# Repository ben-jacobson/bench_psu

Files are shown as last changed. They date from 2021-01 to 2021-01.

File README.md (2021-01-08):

Schematics and ARM Mbed code for a basic adjustable DC bench power supply.

This uses an STM32 MCU to control two channels of adjustable switch mode power supply. Two rotary encoders allow adjustment for voltage on each channel, along with a push button to switch between coarse and fine voltage adjustments. This design makes use of a 12 bit ADC to measure the voltage so that adjustment is made based on measured voltage. 

Each power supply ranges uses the LM2674 which ranges from 1.21V to VDD and is capable of delivering 500mA current. For now there is no current control.

You will need to supply your own 24V DC power supply which is recommended at least 1A. I used a switch mode 24V supply so that there is no need for any additional cooling. The LM2674 maxes out at 36V, but I have not tested anything higher than 24V

Mostly these parts were chosen because I had most of this on hand. This was designed to be an ultra budget build making use of parts from old projects, and to teach me how to build a basic PSU. In future, I'd like to build something that allows current limiting with a 0V to 36V range.

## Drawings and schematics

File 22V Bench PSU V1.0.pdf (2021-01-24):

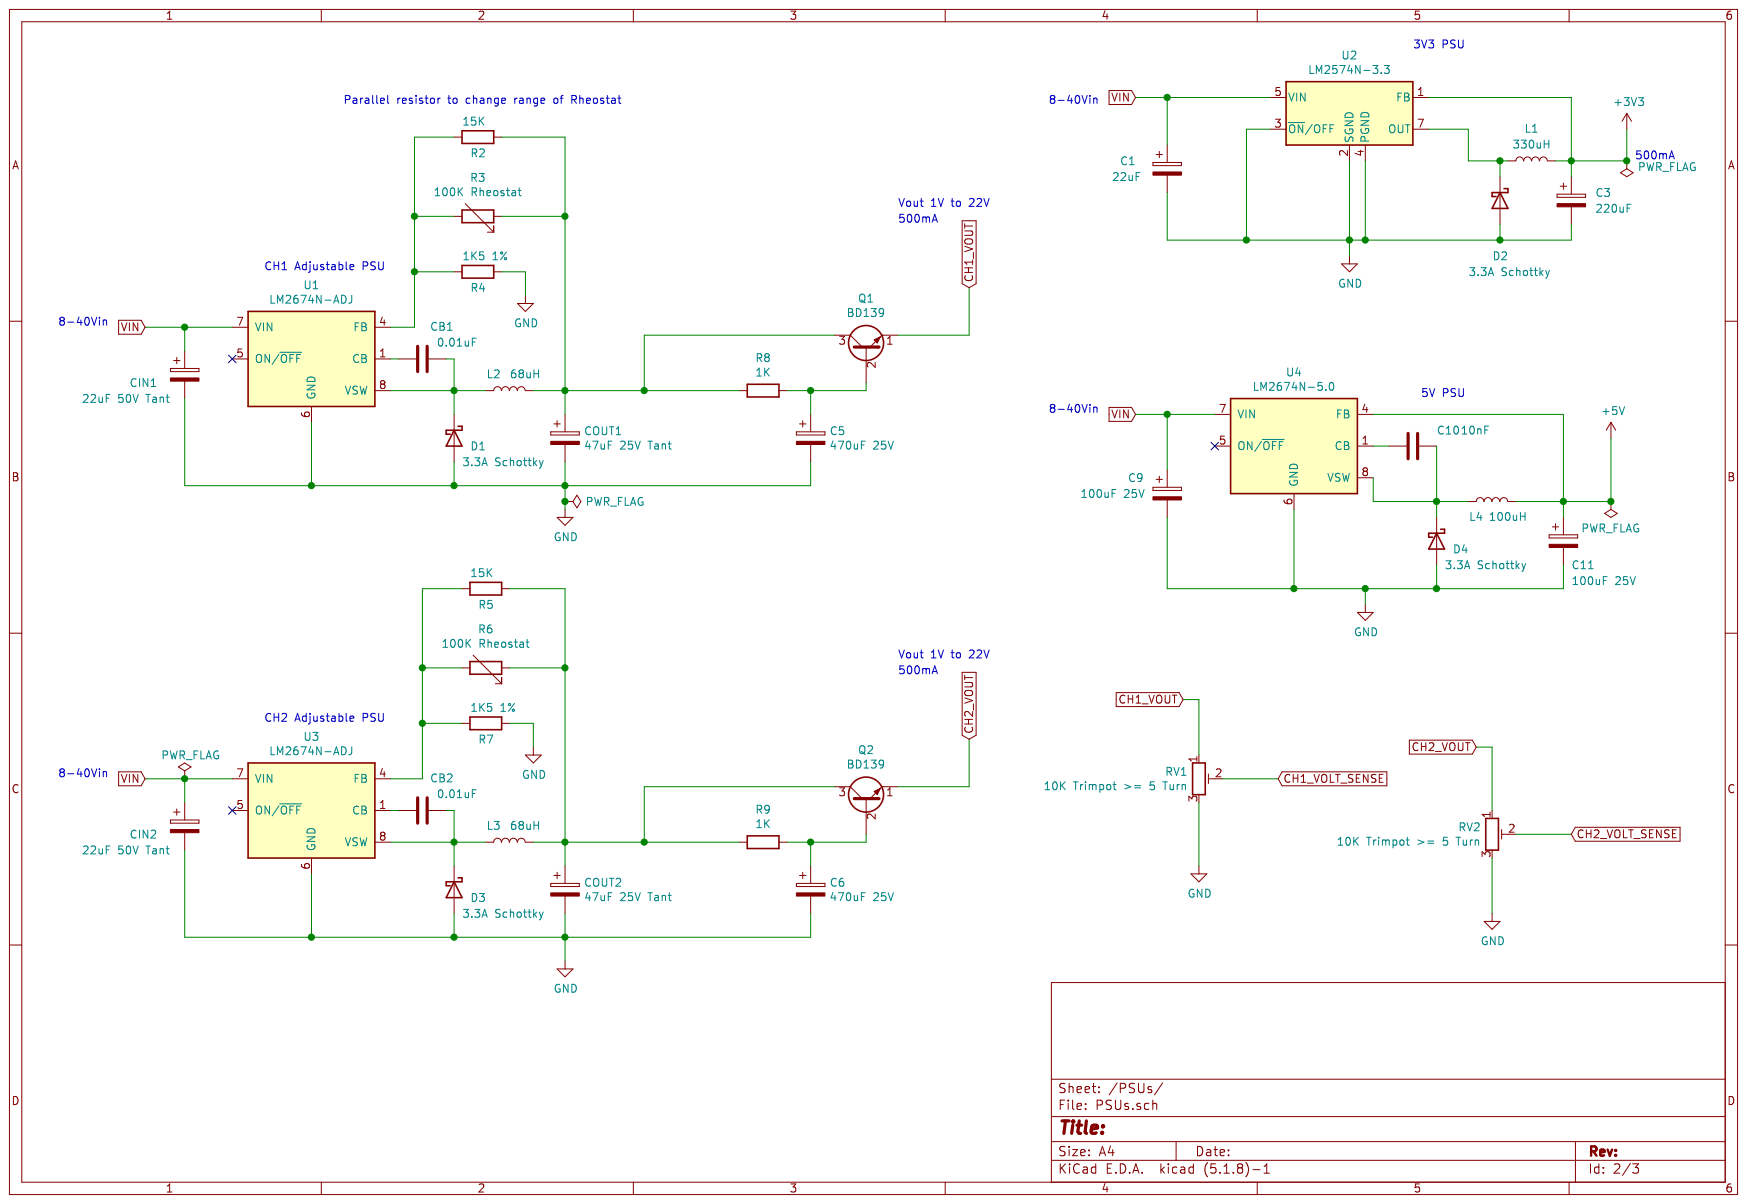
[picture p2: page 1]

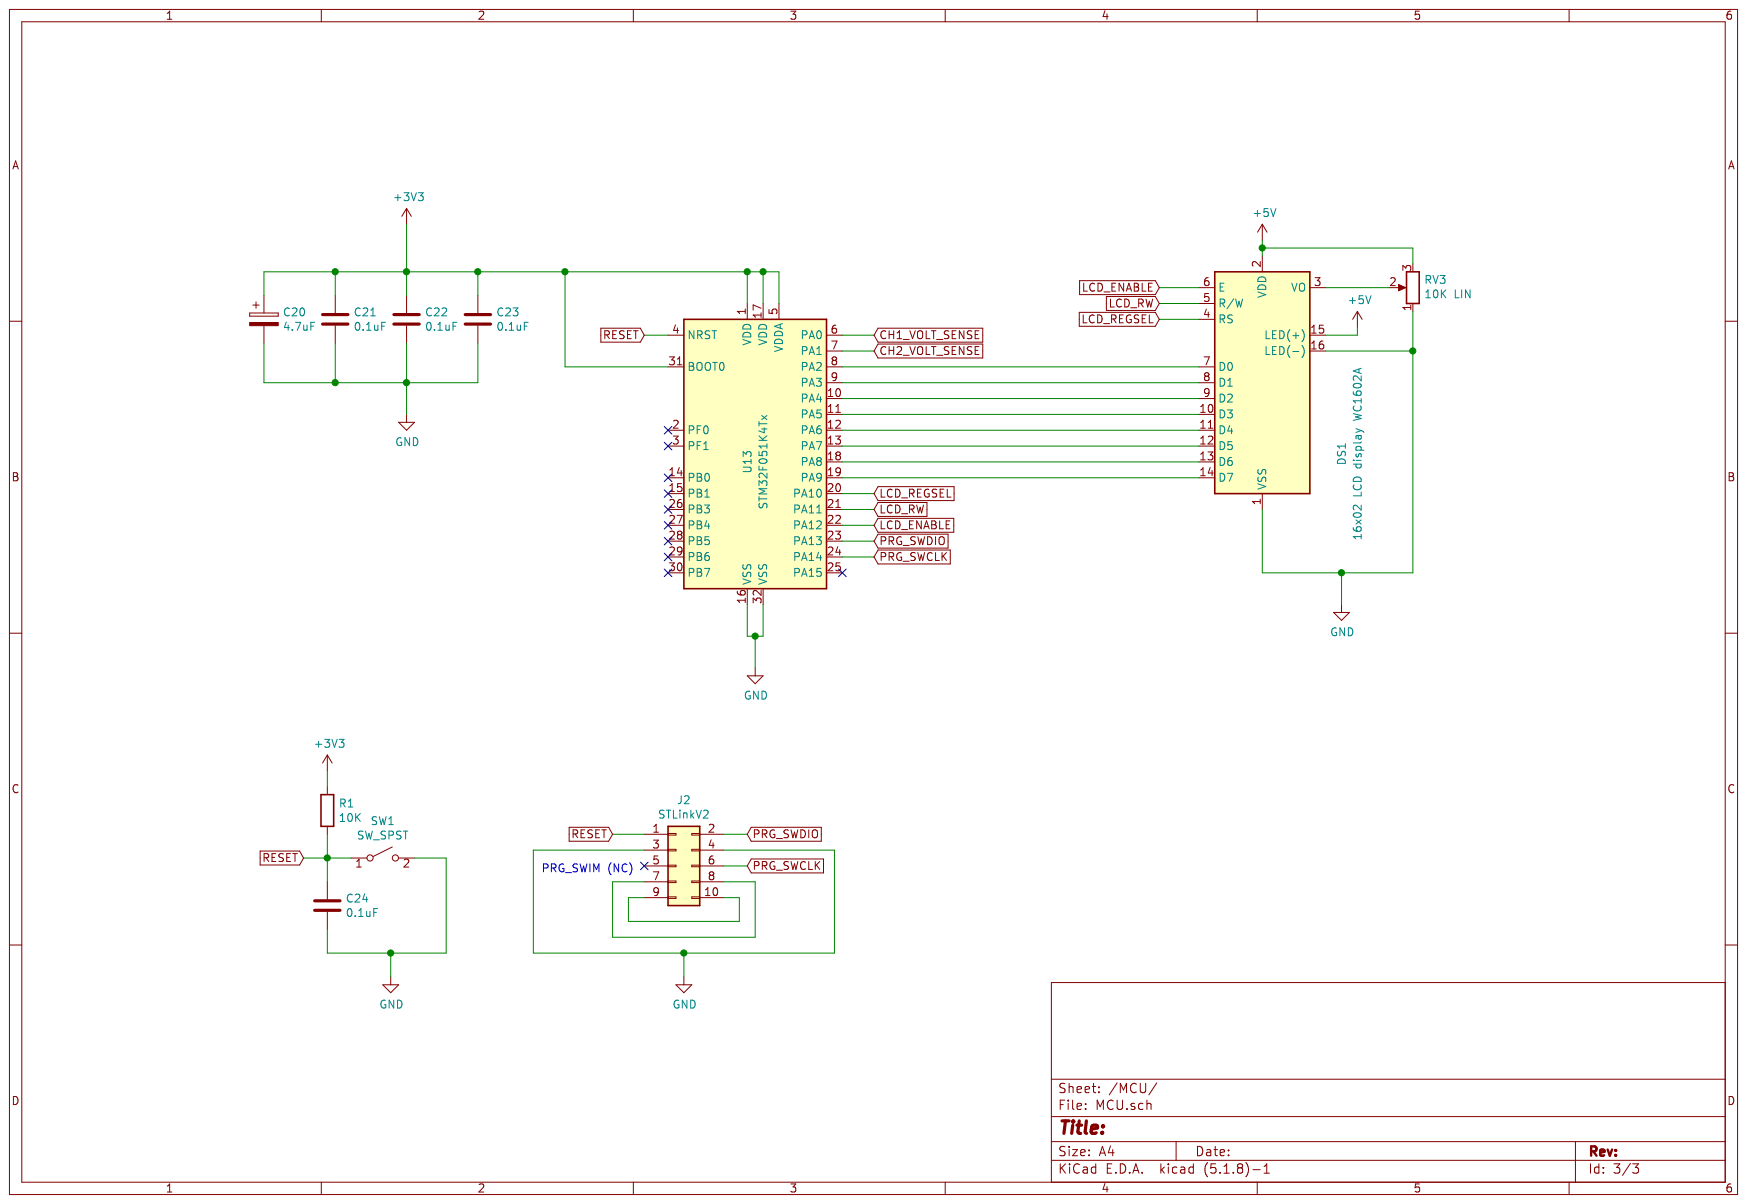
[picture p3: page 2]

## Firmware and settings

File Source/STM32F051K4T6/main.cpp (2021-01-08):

/*
    Requires Mbed-OS 6.5 or later
    See mbed_app.json file, the printf library has been reverted to standard to allow full functionality - in this case, we needed printf to print floats with a set decimal place
*/

#include "mbed.h"
#include "HD4470_HAL.h"
#include "voltmeter_thread.h"

int main() {
/*
    D5-D12 = Data bus D0-D7
    D2 = Register Select
    D3 = Read/Write
    D4 = Enable
*/ 
// PortOut LCD_display_data_bus(PortA); if you want to use a Port, do this
BusOut LCD_display_data_bus(D5, D6, D7, D8, D9, D10, D11, D12); // Otherwise, do this. 
HDD4470_HAL LCD_Display(&LCD_display_data_bus, D2, D3, D4);

// Set up our unused ADC pins as digitalOuts. This helps to reduce ADC error
//DigitalOut unused_A1(A1);
DigitalOut unused_A2(A2);
DigitalOut unused_A3(A3);
DigitalOut unused_A4(A4);
DigitalOut unused_A5(A5);
DigitalOut unused_A6(A6);
DigitalOut unused_A7(A7);
DigitalOut unused_D3(D3);
DigitalOut unused_D6(D6);

constexpr int VOUTSCALE = 10; 
constexpr float AREF = 3.324f;
voltmeter_thread ch_one_voltmeter(A0, AREF, VOUTSCALE);
voltmeter_thread ch_two_voltmeter(A1, AREF, VOUTSCALE);

// Set up our ADC to read the voltage input
//AnalogIn voltage_read_pot(A1, 3.324f * VOUTSCALE); // 3v3 reference voltage, but at 10x scale. // todo - make this adjustable.

    while (true) {
        LCD_Display.set_cursor_position(0, 0);
        LCD_Display.printf("CH1: %.1fV \n", ch_one_voltmeter.get_average_voltage());   // Note, you must enable std printf to allow printing floats - https://github.com/ARMmbed/mbed-os/blob/master/platform/source/minimal-printf/README.md
        LCD_Display.printf("CH2: %.1fV \n", ch_two_voltmeter.get_average_voltage());
        ThisThread::sleep_for(100ms);
    }
}

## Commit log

2020-12-31 added additional IO expanders
    [Bench PSU.sch, DISPLAY.sch, MCU.sch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]
2020-12-31 added digital pots for voltage control
    [MCU.sch, PSUs.sch]
2021-01-01 slight modifications to match the parts we ordered
    [PSUs.sch]
2021-01-01 Switched the MCU to a basic STM32, changed the business logic to 3V3, created a new 3V3 regulator for this. Also initialised code base. We'll use ARM Mbed for rapid development
    [DISPLAY.sch, IO.sch, MCU.sch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]
2021-01-01 had to reload source files. Waiting on the STM32F01 so will compile for target STM32F303 for now. Just a temporary change for now
    [DISPLAY.sch, IO.sch, MCU.sch]
2021-01-01 We now have more MCU pins. Was able to remove two I2C IO expanders
    [DISPLAY.sch, IO.sch, MCU.sch]
2021-01-01 fixed some DRC errors
    [DISPLAY.sch, IO.sch, MCU.sch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]
2021-01-03 ported over LCD display code, modified schematic as we no longer need some of the I2C expanders
    [Bench PSU.kicad_pcb, DISPLAY.sch, MCU.sch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]
2021-01-06 modifications to voltage reading schematic, mocked up code
    [PSUs.sch]
2021-01-07 Created voltmeter objects with their own threads for reading voltages, the intent is to use this to create long averages of values
2021-01-07 voltmeter now takes samples for averaging
2021-01-08 Added capacitance multiplier for reducing psu ripple. Settled on 1 decimal place Voltage adjustment, not the best but we can't seem to get the ADC to settle down
    [PSUs.sch]
2021-01-09 Replaced digital pots with analog, removed spi bus too as no longer needed
    [Bench PSU.sch, DISPLAY.sch, MCU.sch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]
2021-01-09 corrected some psu errors
    [MCU.sch, PSUs.sch]
2021-01-09 exported a PDF of early version, still some assumptions to validate but it's mostly working as intended
    [PSUs.sch]
2021-01-09 replaced capacitor multiplier by using a more powerful output transistor
    [MCU.sch, PSUs.sch]
2021-01-24 fixed error in schematic after building up parts of circuit
    [PSUs.sch]
